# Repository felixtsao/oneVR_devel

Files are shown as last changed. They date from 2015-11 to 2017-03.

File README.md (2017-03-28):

# One VR
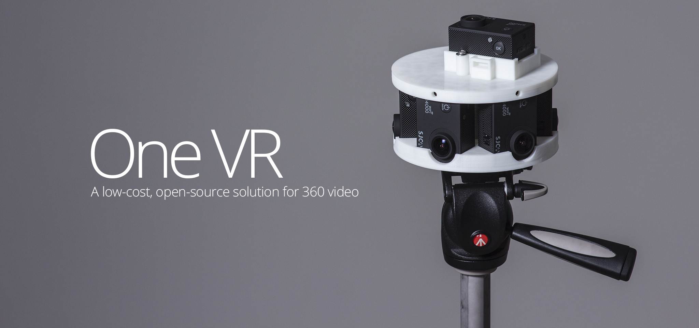
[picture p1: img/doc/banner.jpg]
Banner

<h3> A low-cost, DIY, VR/360 video solution </h3>
<p>
A low-cost, virtual reality, 360 camera system along with a mobile web 360 player application, forms an end-to-end solution; from capture to viewing.
<p>
Designs based around using off-the-shelf hardware/software. Parameterized 3D model files allow for easy generation of camera mounts to fit most small, rectangular cameras like GoPro, SJCAM, Xiaomi and NoPro. Parameterization also allows scalability to reach 4K resolution and beyond. The example SJ4000 rig costs less than $500 USD to build and achieves 4K resolution.
<p>
Video stitching methods include using accessible software and custom scripts provided by this repository.
<p>
Project started Spring break 2015 with some good friends and further developed through a Computational Photography class, CS 534. Hardware resources/funding by Garage Physics at University of Wisconsin, Madison.
<p>
<h4> Example results </h4>

[4K 60fps 8x Xiaomi Yi ITE Building](https://www.youtube.com/watch?v=hQ7O1qrUY-8) <br>
[4K 30fps 7x SJ4000 Vibration Test](https://www.youtube.com/watch?v=YHSJdiMrLIY) <br>
[4K 30fps 6x SJ4000 Madison Capitol](https://www.youtube.com/watch?v=a_FUM7AA19g)

<h3> Motivation </h3>

360 video is an exciting medium that was recently supported by video sharing sites like [YouTube](https://www.youtube.com/channel/UCzuqhhs6NWbgTzMuM09WKDQ), [Facebook](http://newsroom.fb.com/news/2015/09/introducing-360-video-on-facebook/) and [Vimeo](https://join.vimeo.com/360/?vcid=30830). Unfortunately, content creation has remained limited due the high cost-of-entry in acquiring 360 cameras and video stitching software. Professional solutions range from thousands to tens of thousands of dollars and has low accessibility. Cost-friendly, consumer 360 cameras exist on the market but are limited to sub 4K resolutions, which suffer from pixelation in 360 playback.
<p>
This repository aims to provide a high-quality solution while being accessible to 360 filmmakers on a budget. The optimal target cost for a full 360 video solution is under or around $500.
<p>
Additionally, concensus in the creative community is that a different approach from traditional filmmaking techniques must be used in developing meaningful 360 video. This is because applying panning motions and camera dollys like in traditional film may cause excessive disorientation in 360 video. Another challenge is that users may look in directions that are not intended for by the director/news-anchor.
<p>
Increasing accessibility of 360 cameras will allow more creative individuals to contemplate the artistic representation and navigation issues of 360 video. It is only beneficial to allow more people to address the challenge which can improve the collective understanding of art, filmmaking and journalism.

<h3> Pipeline </h3>
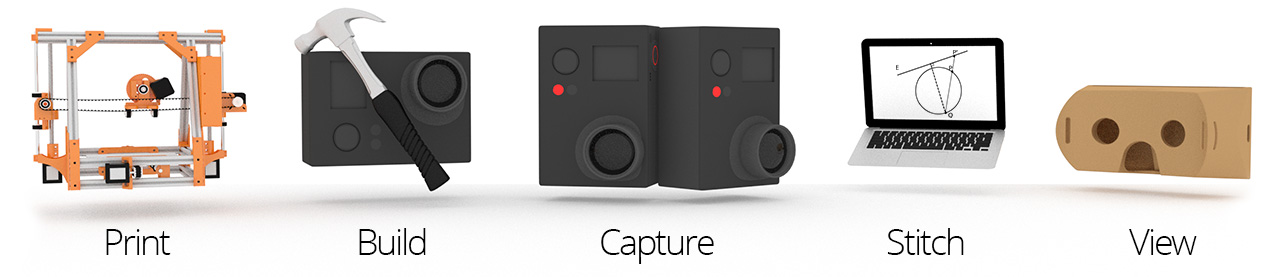
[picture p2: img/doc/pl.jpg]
Pipeline


<h3> Directories </h3>

`/360warper` - A standalone image/video warper to be used with video compositing tools like AFX, Blender, Nuke<br>
`/cam` - 3D printable 360 camera rig files (`.stl`), generator files (`.scad`) and camera control commands <br>
`/cpp` - Automated video stitching (in development, see video tutorial below for manual solution) <br>
`/img` - Documentation, reference and source images <br>
`/viewer` - Basic VR 360 video/image player for web browsers

<h3> Multi-camera system overview </h3>

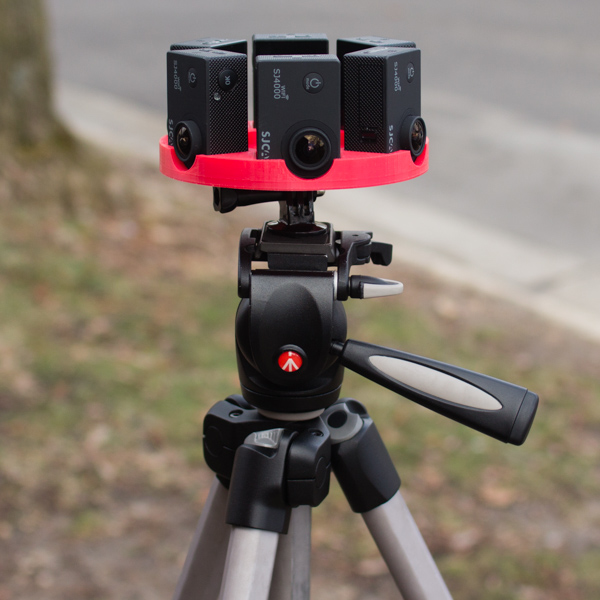
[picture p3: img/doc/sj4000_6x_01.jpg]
Version 2

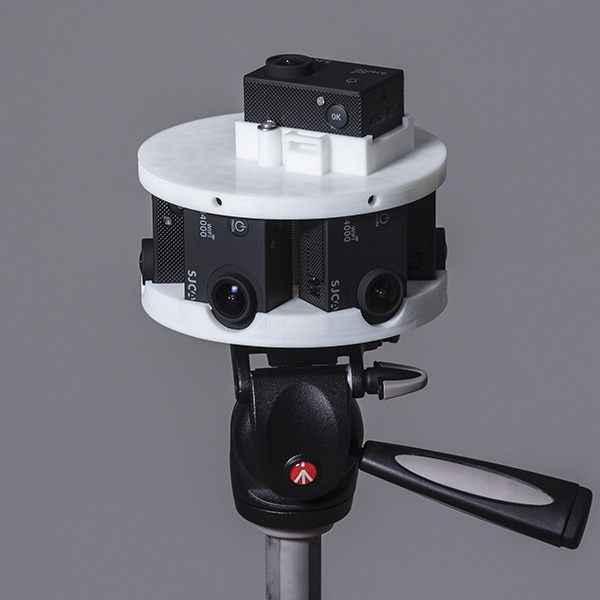
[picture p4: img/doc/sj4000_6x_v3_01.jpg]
Version 3


Version 2 left, pictured without upper mount. Version 3 on right with optional top camera expansion module.

Captures monoscopic video in 360 degrees horizontal and ~135 degrees vertical. Six individual streams are stitched and blended together into a cohesive panoramic video.
<p>
6 SJ4000 cameras arranged outwards is just barely enough information to create a 360 video and requires a decent amount of user input to stitch in After Effects. Using 5 SJ4000 cameras seated horizontally would help automated stitching a lot at the cost of some vertical field of view. Using more cameras is ideal, but drives up cost and requires a more powerful computer for stitching. Modifying lenses of the cameras with wider angle replacements is also a solution. If planning to build with out-of-box SJ4000s oriented vertically, using 8 cameras is a safe option, 7 will be bare minimum.
<p>

<h3> Bill of Materials - Hardware & Software </h3>

Listed below are items I have tested but any of them can be swapped out with other items that serve a similar purpose. Search [3DHubs](https://www.3dhubs.com) to find access to a nearby 3D printer. Some libraries have printers as well. Or build your own [RepRap](http://www.reprap.org) as a support project.

<h5> Hardware </h5>

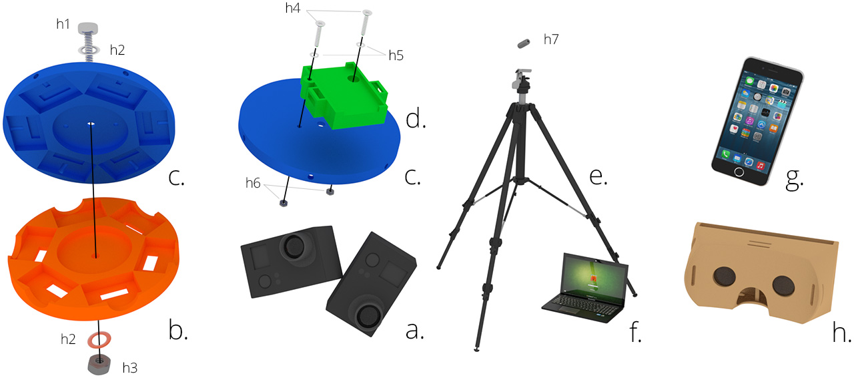
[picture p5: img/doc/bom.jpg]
Bill of Materials


<b>a.</b> 6 or more SJ4000 action cameras (~$60 each), Alternatives include GoPro, Xiaomi (may need to modify 3D models). Can use less cameras by replacing stock lenses with wide angle lenses for Xiaomi and SJ4000.
<br>
<b> b. </b> A lower bracket/apparatus to seat cameras. Modify existing CAD designs in `/cam` directory to meet camera choice.
<br>
<b> c. </b> A matching upper apparatus to secure cameras. Likewise, modify existing CAD designs in `/cam` directory to meet camera choice.
<br>
<b> d. </b> (Optional) Zenith module for housing a single additional zenith camera i.e. "Sky Camera."
<br>
<b> e. </b> Standard Tripod
<br>
<b> f. </b> Standard computer, relatively powerful GPU for image processing preferred
<br>
<b> g. </b> Any mobile device with a modern web browser
<br>
<b> h. </b> A headmounted display to house mobile device for VR viewing like [Cardboard](https://www.google.com/get/cardboard/) or print one from [Thingiverse](http://www.thingiverse.com/search?q=vr+headset).
<p>
<b> h1 </b> - 1x 1/4"-20 bolt for securing top mount to bottom mount. For SJ4000s, length of bolt must be > 3". May be different for other camera selections. Ideally, choose a length that allows bolt to stick past bottom mount an inch or two to connect to tripod with coupling bolt 'h7.'
<br>
<b> h2 </b> - 2x Washers for 1/4"-20 bolt.
<br>
<b> h3 </b> - 1x 1/4"-20 nut for tightening under bottom mount.
<p>
<i>h4 - h6 only applies if using top camera module</i>
<br>
<b> h4 </b> - 2x 6-32 screws (> 1.5" length) to mount top camera expansion module.
<br>
<b> h5 </b> - 4x #6 washers.
<br>
<b> h6 </b> - 2x 6-32 nuts.
<p>
<b> h7 </b> - 1x 1/4"-20 coupling nut for joining entire setup to tripod head.
<p>

(Optional) Switch to gen-lock/sync record controls for cameras, necessary to mitigate rolling shutter when capturing scenes with fast motion, also provides convenience for starting/stopping recording, requires soldering
<center>
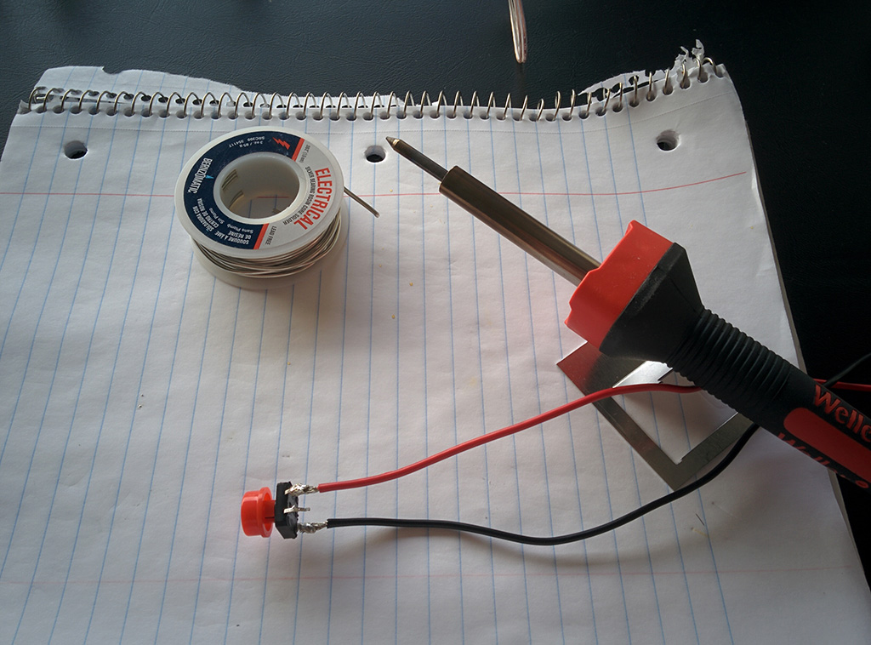
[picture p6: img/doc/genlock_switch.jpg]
Genlock Switch

<center>
<p>

<h5> Software list </h5>

 * [OpenSCAD](http://www.openscad.org) for rapid, parameterized prototyping of 3D printable VR camera mounts (Free)
 * [After Effects CC](http://www.adobe.com/products/aftereffects.html) for basic stitching using warp plugins (Free trial, then monthly subscription)
 * (Optional) Stitching plugins for After Effects like [Skybox Mettle](http://www.mettle.com/product/skybox/), [PTGui](https://www.ptgui.com/), [Kolor](http://www.kolor.com/) or [VideoStitch](http://www.video-stitch.com/) for professional stitching results (> $90)
 * [Blender](https://www.blender.org/) for alternative stitching method to After Effects, also includes capabilites to composite text and 3D. (Free)
 * [YouTube 360 Injector](https://support.google.com/youtube/answer/6178631?hl=en) for tagging proper metadata to final 360 video for properly uploading to YouTube (Free)

<h3> Stitching Techniques</h3>

[Video Tutorial: Hand-stitching in After Effects (Quick)](https://www.youtube.com/watch?v=5elOFvyL4KA) <br>
[Video Tutorial: Hand-stitching (Detailed using 360warper script)](https://www.youtube.com/watch?v=F78drmyd21I)<br>
<i>or</i> <br>
For fully automated process,compile and run stitcher in `/cpp` (still in the works) <p>

Stitcher uses ORB feature descriptor pairs to register overlapping images. ORB is also free from patent restrictions.
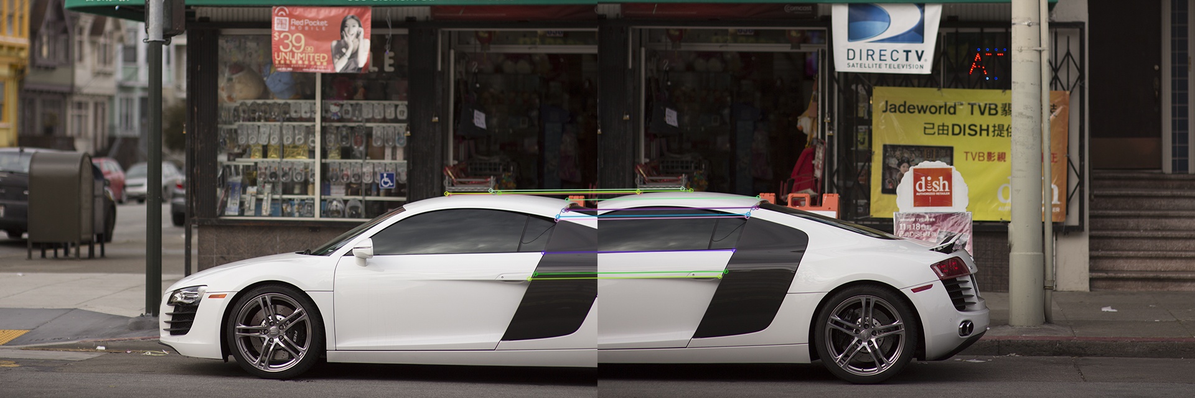
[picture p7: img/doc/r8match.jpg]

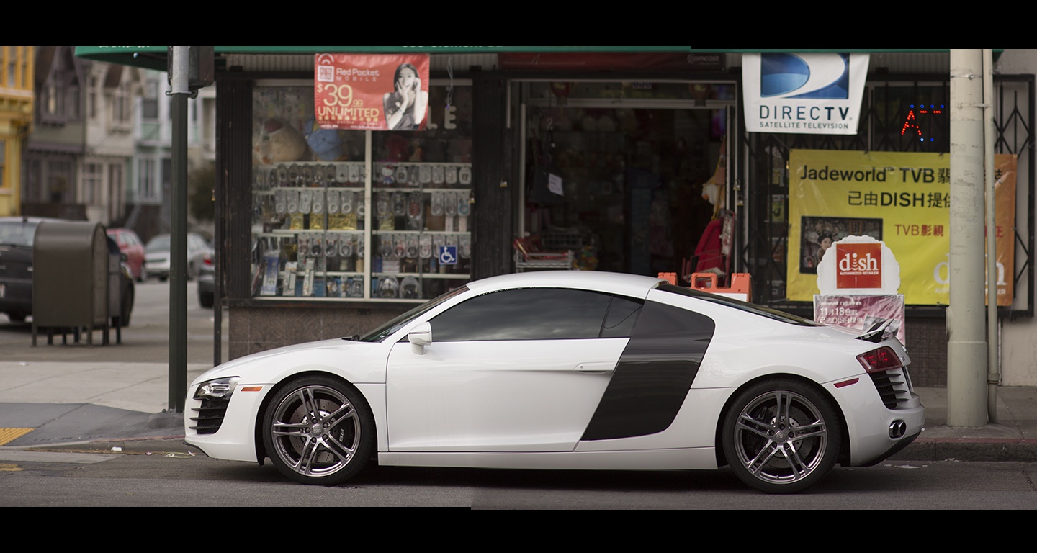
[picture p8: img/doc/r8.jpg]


<h3> Viewing </h3>

Web VR 360 Player - [Demo Link](https://cdn.rawgit.com/felixtsao/oneVR_devel/master/viewer/index.html)
<p>
Visit `/viewer` directory for usage and source code.

<h3> 3D Printing </h3>

Print camera mount yourself or find a local printer through [3DHubs](https://www.3dhubs.com) or the local library.

Older version of `mono_lower_6x_sj4000.stl` printed on a Makerbot Replicator 2 with Red PLA. The mount takes about 4 hours to print if things go smoothly! Newer version of mount printed on an open-source Prusa i3 design, right, with a layer height of 0.27mm through a 0.4mm extruder nozzle.

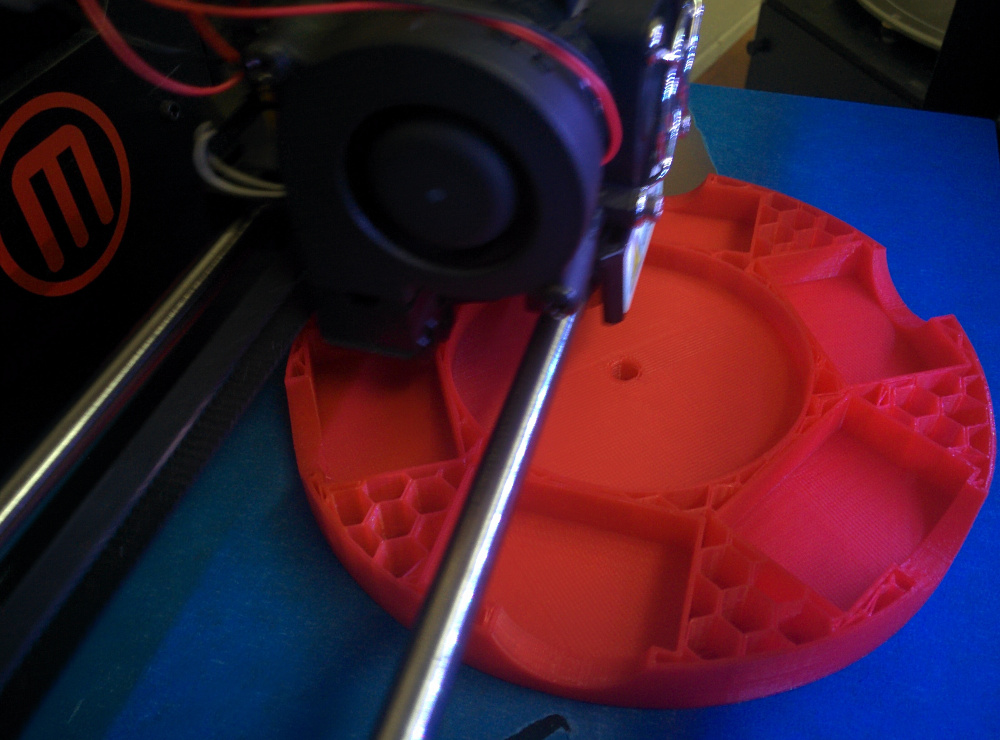
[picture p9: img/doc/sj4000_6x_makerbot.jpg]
Makerbot

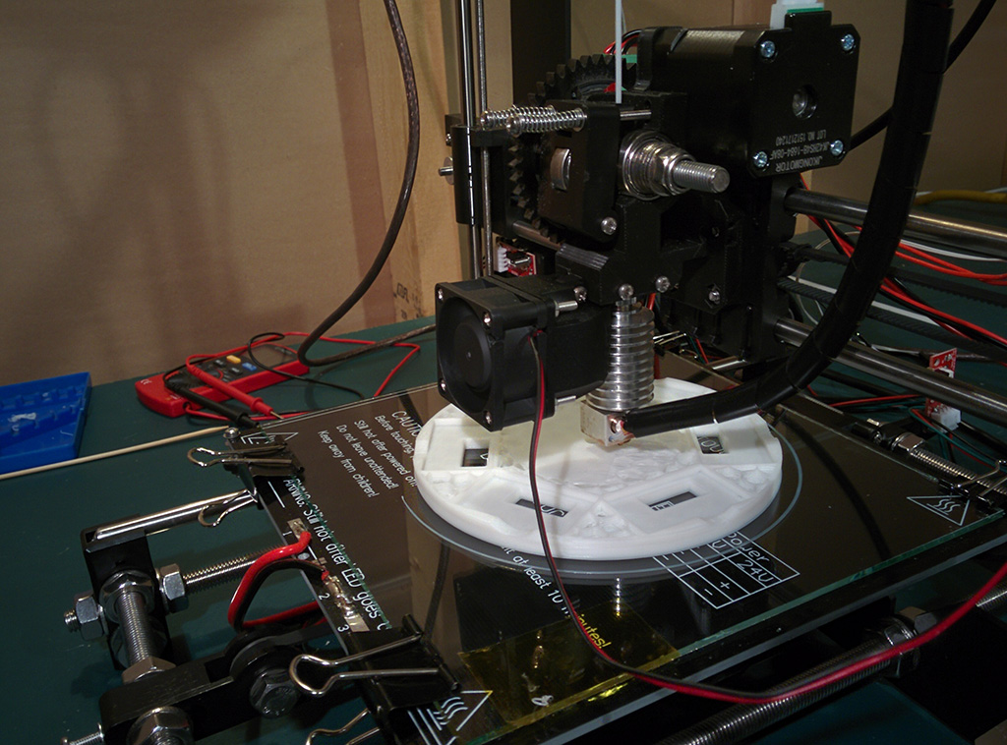
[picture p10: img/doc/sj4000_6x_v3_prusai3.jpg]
Prusa i3


<h5> Creating a new camera mount </h5>

Files are located in `/cam` directory, organized by camera model. To create a new camera mount, open the closest existing `.scad` file and adapt it by changing the camera trench dimensions. Camera dimensions are listed as variables at the top of the `.scad` files and should globally change the trench sizes across the mount. To add more cameras, simply increase the distance of the optical center and make additional copies of the trenches and assign each trench with the appropriate angle. The numbers are technically unitless but they default to millimeter for most printers. Be sure to add 1 to the value used for the camera dimension for a little breathing room.

<h3> // TODO </h3>

 * Create automated video stitching (Implement feature detector)
 * <strike>Top/bottom camera transform for AFX stitch method using Blender or script</strike><br>
 * <strike>Make video tutorial for hand-stitching 360 videos in AFX</strike>

<h3> Technical References </h3>

1) [Course: Computational Photography CS534, UW-Madison, Dyer](http://pages.cs.wisc.edu/~dyer/cs534/) <br>
2) [Text: Chapter 9, Computer Vision, Szeliski](http://szeliski.org/Book/) <br>
3) [Paper: ORB Feature Descriptor, Rublee](http://www.vision.cs.chubu.ac.jp/CV-R/pdf/Rublee_iccv2011.pdf) <br>
4) [Docs: OpenCV](http://docs.opencv.org/3.1.0/) <br>
5) [Docs: ThreeJS](https://threejs.org/) <br>
6) [Docs: RepRap](http://www.reprap.org/)

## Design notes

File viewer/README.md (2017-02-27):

# web360viewer

This viewer is deprecated. Visit [Aframe](https://aframe.io) for a better 360/VR web viewer.
<p>
#
Basic JavaScript/WebGL 360 video/photo viewer for web browsers. Works best on Chrome.
<p>
[Example](https://cdn.rawgit.com/felixtsao/oneVR_devel/master/viewer/index.html)

<h3> Brief Usage </h3>
Specify desired video/photo in file `/js/viewer.js` or rename video/photo file as `/video/src.mp4` or `/img/src.jpg`
<p>
Player default is on video mode, to view photo, set `var play_video = false;` in the file `/js/viewer.js`
<p>
Player default and current implementation only supports equirectangular projection/media. File `/js/viewer.js` includes switch for selecting projection type for future expansion i.e. cubic, pyramidal etc.
<p>
Launch `index.html` in a web browser to play. Can be hosted online and can be viewed on mobile devices using head mounted displays like cardboard.

<h3> Bugs </h3>
* May need to swipe up on the address bar to enable fullscreen on iOS devices.
* Player may appear to freeze when buffering as no buffering icon is displayed.

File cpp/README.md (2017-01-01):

# Radial Stitcher (radStitch)

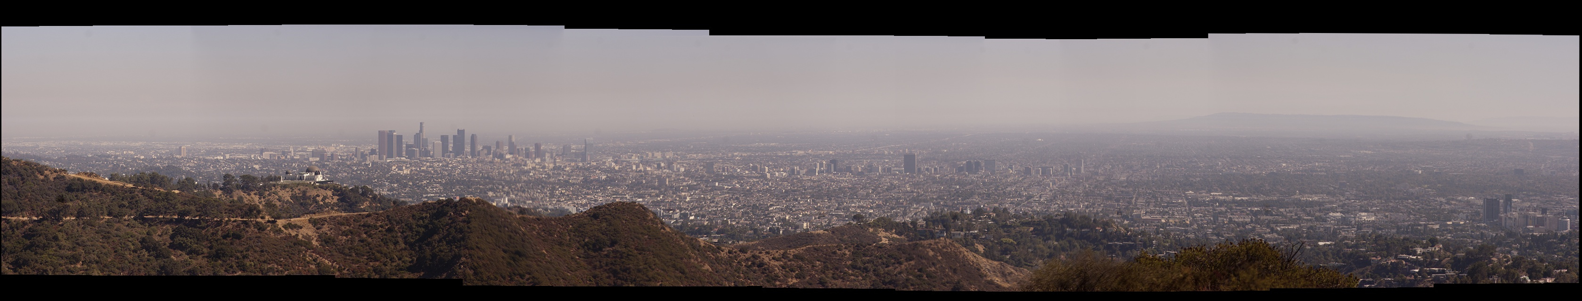
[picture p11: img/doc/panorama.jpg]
Banner


A simple panorama stitcher. Assumes input images are taken from radially symmetric viewpoints relative to common optical center--like the camera shown on the main page and like the Google Jump camera. Uses OpenCV feature description to generate matching landmarks between adjacent images. Requires OpenCV to be installed in order to compile. Works with OpenCV 3.1.0 installed on Ubuntu 16.04

<h3> Brief Usage (Ubuntu 16.04, OpenCV 3.1.0)</h3>
<i> You can probably massage this to run in Windows and macOS since using `cmake`, I haven't tried yet.</i>
<p>
To compile, make sure OpenCV is installed, and in a terminal, navigate to directory with `main.cpp` and `CMakeLists.txt`, run:
```
cmake .
```
Staying in the same directory, run:
```
make
```
After compilation, still in same directory, to stitch images, run:
```
./radStitch <image1> <image2> ... <imageN>
```
Test with images found in `/img/pano`
<p>
<i>Current constraints:</i>
<br>
Neighboring images specified in command line need to have an overlapping region i.e. `<imageK>` and `<imageK+1>` must share an overlapping region

<h3> // TODO </h3>
Currently works with images, will need to extend to video using `ffmpeg` or something
<br>
Need to implement polar wraparound
<br>
Code for parallel hardware, GPU
<br>
3D?

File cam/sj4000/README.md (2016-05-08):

<h3> Notes </h3>
SJ4000 and Elecam have the same dimensions so the mounts in this directory fit both types of cameras. However, i/o cutouts are for SJ4000 and have not been verified to be in the same locations as elecam, so usb/sdcard slots may be blocked by the mount.
<p>
Rendered `.stl` files are to be directly printed on a 3D printer. To find a local 3D printer visit [3DHubs](https://www.3dhubs.com)
<p>
Use `.scad` files in [OpenSCAD](http://www.openscad.org) (Free) to modify dimensions to match camera type and other aspects of camera mount. Render to `.stl` when finished to print.

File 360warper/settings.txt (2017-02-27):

// For additional information, check the readme.txt or
// see the accompanying YouTube tutorial at:
// https://www.youtube.com/watch?v=F78drmyd21I
//
// Settings file for 360warper. Please specify the following options below to
// let the warper know how to properly warp/project your image/video.
// You must specify the effective field of view (fov) or program will not run.
// For all other settings, if not specified in this file, 360warper will use
// the following default values: (r = up = k1 = k2 = k3 = clip = debug = 0)
// Default resolution is 4096 x 2048. You can tell the program to ignore certain
// lines of settings by typing any character at the beginning of the line. e.g.
// this comment block has "//" before each line. The setting below is ignored
// fov 120
// Be sure a setting's keyword begins immediately at the beginning of the line
// followed by a single space and then the value to guarantee proper function.
//
// resolution:
//     Target horizontal equirectangular output resolution, vertical
//     resolution is automatically chosen to be half the horizontal i.e.
//     2:1 aspect ratio
// up:
//     Enables up/top camera warping. Set true (1) to enable or set false (0) to
//     project input image/video to side/equator of sphere
// fov:
//     Effective field of view after distortion correction. This may not be
//     the same field of view advertised by camera product labels since some
//     pixels become unusable after distortion correction. See camera presets.
// k1, k2, k3:
//     Lens distortion correction values. If your camera has lens correction
//     settings from the manufacturer, it is recommended to use those and then
//     use all zeros for k1, k2, k3 for no distortion correction. Also see
//     camera presets below to use correct values for k1, k2, k3. You may also
//     experimentally determine k1, k2, k3 by taking an image of a checkerboard
//     and changing values until the lines become straight or use other
//     programs like ImageMagick, OpenCV, Numpy, Matlab etc...
// clip:
//     You usually want this on when rendering entire video streams. Set true
//     (1) to clip away any part of the frame that input image/video does not
//     project to. Set false (2) to include the rest of the 360 frame. This is
//     helpful when you want to see how a single image/video looks in 360 since
//     the frame maintains the correct proportions when shown in a 360 viewer.
// debug:
//     Draw longitude and latitude lines over warped video.

// Choose settings below
// ------------------------------------------------------------------

resolution 4096
up 0
r -90 
clip 1
debug 0
fov 97.32
k1 0.27
k2 -0.0232
k3 -0.006

// ------------------------------------------------------------------
// Choose settings above

// Presets:
// Xiaomi Yi Action Camera (Sony EXMOR R Sensor, Ambarella A7LS processor)
// fov 97.32
// k1 0.27
// k2 -0.0232
// k3 -0.006

// -----------------------------------------------------------------
// Author: hello@felixtsao.com

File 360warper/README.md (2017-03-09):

#360warper

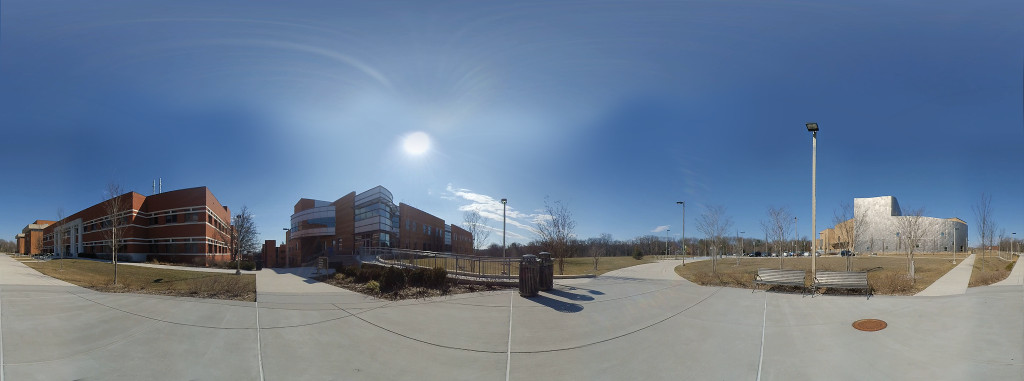
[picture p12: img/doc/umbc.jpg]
UMBC


A standalone image/video warper created to be used with video compositing tools like After Effects, Blender, Nuke etc. to create 360 video.
<p>
Transforms raw footage from camera to correct projection onto a spherical/equirectangular map for 360 video. Shown below is an example of projection to the top/north pole and projection to side/equator of the 360 viewing sphere.

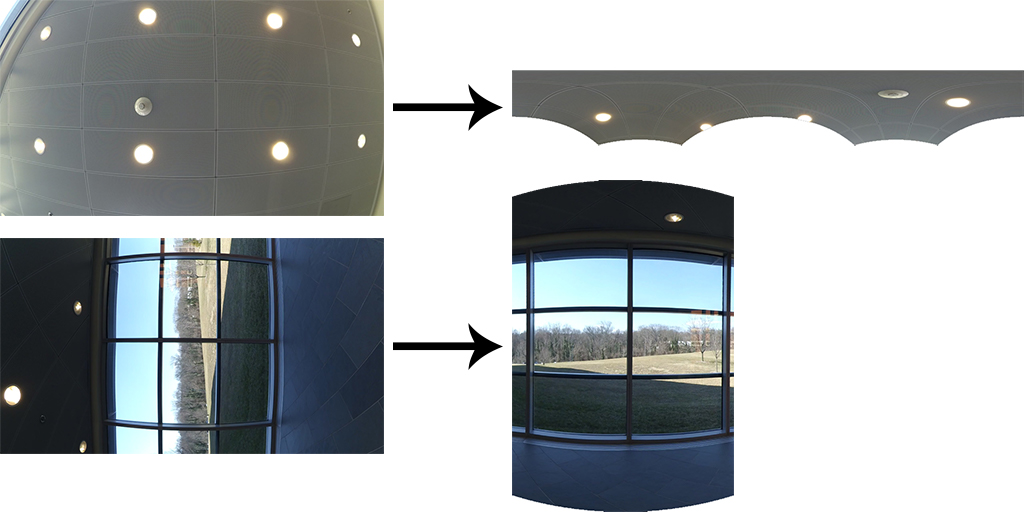
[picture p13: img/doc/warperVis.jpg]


Executables and warper script is available to download for: <br>
[macOS64](https://mega.nz/#!5UUGCYzC!riW7KApZu_tcmvv7iLBDX5ToDQJTHDBUizHfy2Ga2bs) <br>
[Win64](https://mega.nz/#!QY81lZrK!gdPLD3h7vp4k75xlDRuZmhUMljWqKGRqeY87K5DeIPQ) <br>

To see the accompanying YouTube tutorial visit:
https://www.youtube.com/watch?v=F78drmyd21I

To run warper, open a terminal and change to directory (`cd` command) containing all necessary files i.e.

    warp.py
    360warper
    settings.txt
    ffmpeg (3.2.4 included here, visit ffmpeg.org for more info)
    < Any image/video files to warp >(.mp4, .jpg, .png)

Confirm and change parameters in `settings.txt` file for desired use.

When ready to warp images/videos, type in the terminal command:

    ./warp.py video1.mp4 video2.mp4 checkerboard.jpg ...

Warping process will run. May take some time.

Process will automatically create and delete a temporary working directory called `/temp` in the same directory.

Warped videos will be saved as `originalName_warped.mp4` in same directory

Warped images will be saved as `originalName_warped.jpg` in same directory

Lens distortion correction can also be handled by `360warper`. Use the presets in the `settings.txt` file or experimentally determine the correct distortion for desired camera by taking images of several checkerboards and tweaking the distortion settings in the `settings.txt` file until it looks acceptable.

<h3> // TODO </h3>
* Pipeline and multi-thread the code more for CPU
* Implement GPU version
* Learn ffmpeg and avlib and interface directly with warper program to replace the current random python hack.

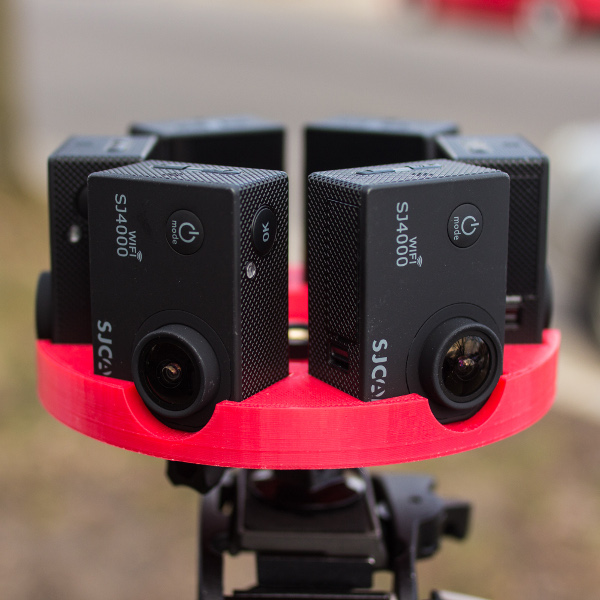
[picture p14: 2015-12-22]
img/doc/sj4000_6x_02.jpg

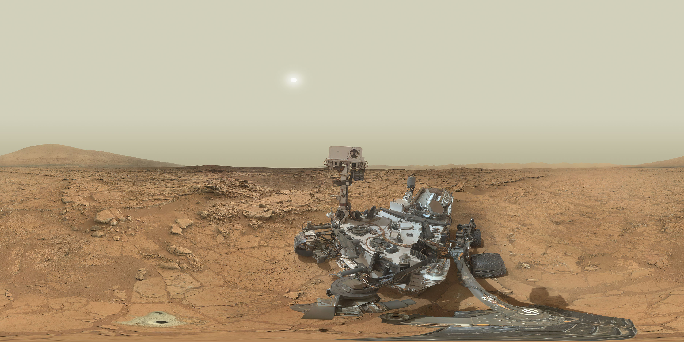
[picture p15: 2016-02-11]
viewer/img/src.jpg

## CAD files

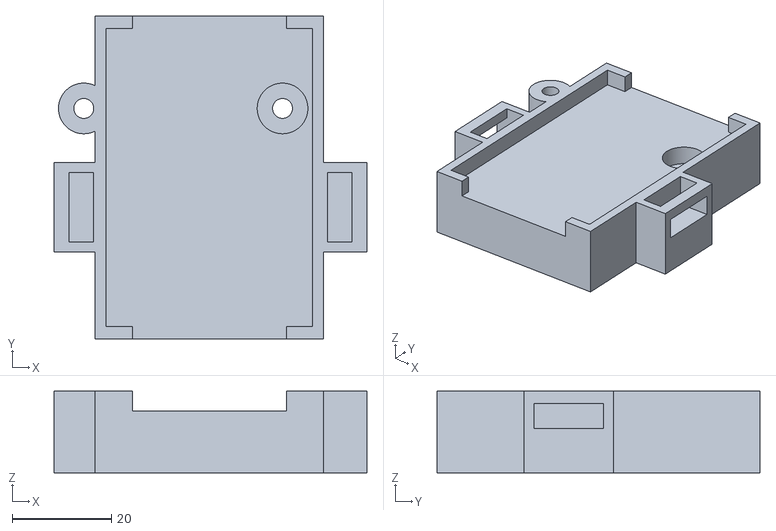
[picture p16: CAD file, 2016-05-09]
cam/sj4000/mono_zenith_sj4000.stl
63.0 x 65.0 x 16.5

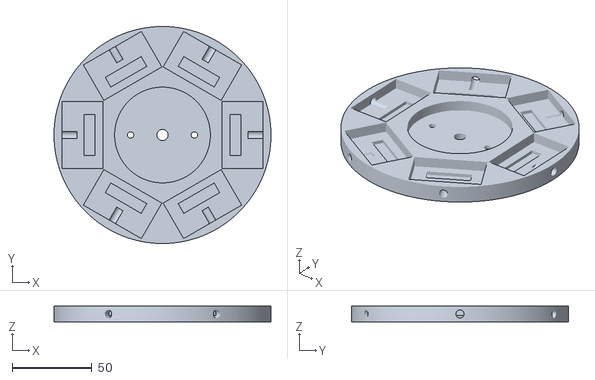
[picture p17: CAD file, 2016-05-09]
cam/sj4000_elecam/mono_upper_6x_sj4000.stl
136.0 x 136.0 x 10.0

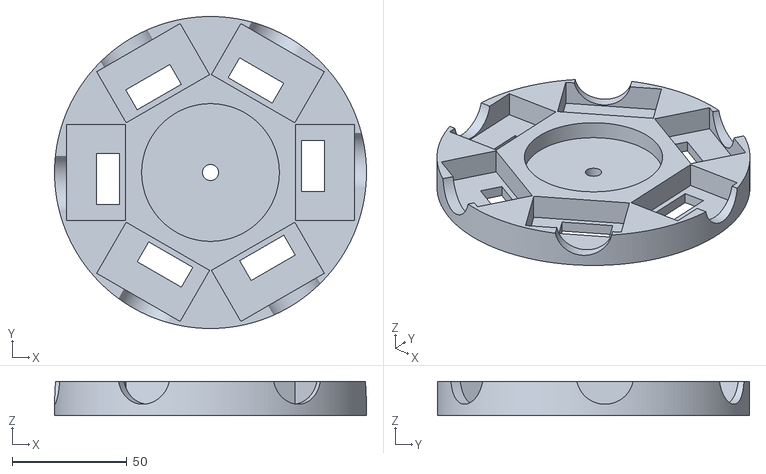
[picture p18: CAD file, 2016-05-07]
cam/sj4000_elecam/mono_lower_6x_sj4000.stl
136.0 x 136.0 x 15.0

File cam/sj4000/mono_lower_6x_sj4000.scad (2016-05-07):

$fn=200;

distance = 50; // distance from optical center

// trench dimensions (mm)
// add 1 to dimension for a little wiggle room
width = 42;
length = 25.7; 
depth = 12;

// lens cutout params
lenset = 5;
lenslift = -10;
lensdist = (distance + 12);

num_cameras = 6; // number of cameras
angular_disp = 360 / num_cameras; // angle between each camera

difference(){

    // apparatus
    cylinder(h = 15, r = 1.36 * distance, center = true);

    // trench holding camera 0
    translate([distance, 0, 3]){
        cube(size = [length, width, depth], center = true);
        translate([-5.35, 2.9, 0])
        cube(size = [10, 22.2, 100], center = true);
    }
    rotate([0,90,0])
    translate([lenslift, lenset, lensdist])
    cylinder(h = 12, r = 12.5, center = true);
 
        
    // trench holding camera 1
    rotate([0,0, angular_disp * 1]){
    translate([distance, 0, 3]){
        cube(size = [length, width, depth], center = true);
        // bottom i/o cutout
        translate([-5.35, 2.9, 0])
        cube(size = [10, 22.2, 100], center = true);
    }
    rotate([0,90,0])
    translate([lenslift, lenset, lensdist])
    cylinder(h = 12, r = 12.5, center = true);
    }

    // trench holding camera 2
    rotate([0,0, angular_disp * 2]){
    translate([distance, 0, 3]){
        cube(size = [length, width, depth], center = true);
        translate([-5.35, 2.9, 0])
        cube(size = [10, 22.2, 100], center = true);
    }
    rotate([0,90,0])
    translate([lenslift, lenset, lensdist])
    cylinder(h = 12, r = 12.5, center = true);
    }

    // trench holding camera 3
    rotate([0,0, angular_disp * 3]){
    translate([distance, 0, 3]){
        cube(size = [length, width, depth], center = true);
        translate([-5.35, 2.9, 0])
        cube(size = [10, 22.2, 100], center = true);
    }
    rotate([0,90,0])
    translate([lenslift, lenset, lensdist])
    cylinder(h = 12, r = 12.5, center = true);
    }

    // trench holding camera 4
    rotate([0,0, angular_disp * 4]){
    translate([distance, 0, 3]){
        cube(size = [length, width, depth], center = true);
        translate([-5.35, 2.9, 0])
        cube(size = [10, 22.2, 100], center = true);
    }
    rotate([0,90,0])
    translate([lenslift, lenset, lensdist])
    cylinder(h = 12, r = 12.5, center = true);
    }

    // trench holding camera 5
    rotate([0,0, angular_disp * 5]){
    translate([distance, 0, 3]){
        cube(size = [length, width, depth], center = true);
        translate([-5.35, 2.9, 0])
        cube(size = [10, 22.2, 100], center = true);
    }
    rotate([0,90,0])
    translate([lenslift, lenset, lensdist])
    cylinder(h = 12, r = 12.5, center = true);
    }

    // center dip feature
    translate([0, 0, depth - 6])
    cylinder(h = 12, r = 30, center = true);

    // clearance, not tap, hole for 1/4 20 bolt,
    cylinder(h = 30, r = 3.5, center = true);
    
    // bottom washer, nut
    translate([0, 0, depth - 6])
    cylinder(h = 12, r = 30, center = true);

}


// model sjcam4000 cameras

/*
translate([-50, 0, 27])
rotate([-90, 0, 180])
union(){ // sj400cam
    // camera body
    color("dimgray")
    cube(size = [24.7, 60, 41], center = true);

    // lens
    color("deepskyblue")
    translate([12, 16, 6])
    rotate([0,90,0])
    cylinder(h = 5, r = 10, center = true);

    // power button
    color("gray")
    translate([12, -19, 8])
    rotate([0,90,0])
    cylinder(h = 2, r = 5, center = true);

    // ok button
    color("gray")
    translate([0, -19, 21])
    cylinder(h = 2, r = 5, center = true);
}
*/

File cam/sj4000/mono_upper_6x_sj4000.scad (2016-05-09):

$fn=200;

distance = 50; // distance from optical center

// trench dimensions (mm)
// add 1 to dimension for a little wiggle room
width = 42;
length = 25.7; 
depth = 8;
lift = 3;

difference(){

    // outer radius
    cylinder(h = 10, r = 1.36 * distance, center = true);

    // camera 1 trench
    translate([distance, 0, lift]){
        union(){
            cube(size = [length, width, depth], center = true);
            translate([-4.284, 0, 0])
            cube(size = [7, 26, 12], center = true); //rocker buttons
        }

        // directional microphone cutout
        rotate([0,90,0])
        translate([3,0,11])
        cylinder(h = 15, r = 2.5, center = true);
    }

    // camera 2 trench
    rotate([0,0,60])
    translate([distance, 0, lift]){
        union(){
            cube(size = [length, width, depth], center = true);
            translate([-4.284, 0, 0])
            cube(size = [7, 26, 12], center = true); //rocker buttons
        }
        
        // directional microphone cutout
        rotate([0,90,0])
        translate([3,0,11])
        cylinder(h = 15, r = 2.5, center = true);
    }
    
    // camera 3 trench
    rotate([0,0,120])
    translate([distance, 0, lift]){
        union(){
            cube(size = [length, width, depth], center = true);
            translate([-4.284, 0, 0])
            cube(size = [7, 26, 12], center = true); //rocker buttons
        }
        
        // directional microphone cutout
        rotate([0,90,0])
        translate([3,0,11])
        cylinder(h = 15, r = 2.5, center = true);
    }

    // camera 4 trench
    rotate([0,0,180])
    translate([distance, 0, lift]){
        union(){
            cube(size = [length, width, depth], center = true);
            translate([-4.284, 0, 0])
            cube(size = [7, 26, 12], center = true); //rocker buttons
        }
        
        // directional microphone cutout
        rotate([0,90,0])
        translate([3,0,11])
        cylinder(h = 15, r = 2.5, center = true);
    }

    // camera 5 trench
    rotate([0,0,240])
    translate([distance, 0, lift]){
        union(){
            cube(size = [length, width, depth], center = true);
            translate([-4.284, 0, 0])
            cube(size = [7, 26, 12], center = true); //rocker buttons
        }
    
        // directional microphone cutout
        rotate([0,90,0])
        translate([3,0,11])
        cylinder(h = 15, r = 2.5, center = true);
    }

    // camera 6 trench
    rotate([0,0,300])
    translate([distance, 0, lift]){
        union(){
            cube(size = [length, width, depth], center = true);
            translate([-4.284, 0, 0])
            cube(size = [7, 26, 12], center = true); //rocker buttons
        }
        
        // directional microphone cutout
        rotate([0,90,0])
        translate([3,0,11])
        cylinder(h = 15, r = 2.5, center = true);
    }

    // center dip
    translate([0, 0, lift])
    cylinder(h = 8, r = 30, center = true);

    // clearance hole for 1/4 20 bolt
    cylinder(h = 20, r = 3.5, center = true);
    
    // clearance holes for optional 6-32 top camera bolt
    translate([20, 0, 0])
    cylinder(h = 20, r = 2, center = true);
    translate([-20, 0, 0])
    cylinder(h = 20, r = 2, center = true);
}


// model sjcam4000 cameras

/*
translate([-50, 0, 29.5])
rotate([90, 0, 180])
union(){ // sj400cam
    // camera body
    color("dimgray")
    cube(size = [24.7, 60, 41], center = true);

    // lens
    color("deepskyblue")
    translate([12, 16, 6])
    rotate([0,90,0])
    cylinder(h = 5, r = 10, center = true);

    // power button
    color("gray")
    translate([12, -19, 8])
    rotate([0,90,0])
    cylinder(h = 2, r = 5, center = true);

    // ok button
    color("gray")
    translate([0, -19, 21])
    cylinder(h = 2, r = 5, center = true);
}
*/

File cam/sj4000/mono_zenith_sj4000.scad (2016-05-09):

$fn = 200;


difference(){

union(){
    // stage
    translate([-17.74,-46.4,0])
    cube(size = [46,65,16.5], center = false);
        
    // 6-32 screw hole well
    translate([-20, 0, 8.25])
    cylinder(h = 16.5, r = 5.1, center = true);
    
    // velcro slot 1
    translate([-26, -28.9, 0])
    cube(size = [9,18,16.5], center = false);
    
    // velcro slot 2
    translate([28, -28.9, 0])
    cube(size = [9,18,16.5], center = false);
    
    
}

// sj4000
translate([-15.49,-43.9,12.5])
cube(size = [41.5,60,24.7], center = false);

// io, rocker cutout    
translate([-10.24,-50,12.5])
cube(size = [31,100,24.7], center = false);

// center screw head clearance
cylinder(h = 20, r = 9, center = true);
    
// 6-32 clearance for mounting screws onto upper lid
translate([20, 0, 0])
cylinder(h = 100, r = 2, center = true);
translate([-20, 0, 0])
cylinder(h = 100, r = 2, center = true);

// 6-32 counter-sink
translate([20, 0, 11])
cylinder(h = 6, r = 5.1, center = true);

// velcro cutout 1
translate([-23, -26.9, 12])
cube(size = [5,14,5], center = false);
translate([-27, -26.9, 9])
cube(size = [9,14,5], center = false);

// velcro cutout 2
rotate([0,0,180]){
translate([-34, 12.9, 12])
cube(size = [5,14,5], center = false);
translate([-38, 12.9, 9])
cube(size = [9,14,5], center = false);
}
    

}

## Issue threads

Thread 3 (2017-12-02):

6 camera rig - question

gzalles, 2017-12-02:
Do you think it is possible to stitch a 6 camera rig using your method for free? In Blender or AfterEffects?

Love your work man.

Keep it up!

felixtsao, 2017-12-11:
Yeah, should be possible, will probably take some work though.

If you're using a fairly wide angle lenses for your cameras, you'll need to remove the distortion first before stitching in AE or Blender.

gzalles, 2018-01-22:
I am using 1440 or 4k with wide FOV to get the overlap between cameras. I guess I just have to try and see if it works. I am going to give the Blender method a go (hopefully this week) and let you know how it goes!

Much respect, this contribution is fantastic.

I shared it with a friend of mine who put his own rig together!!!

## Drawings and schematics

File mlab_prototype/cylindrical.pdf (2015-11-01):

# Cylindrical Projection

x

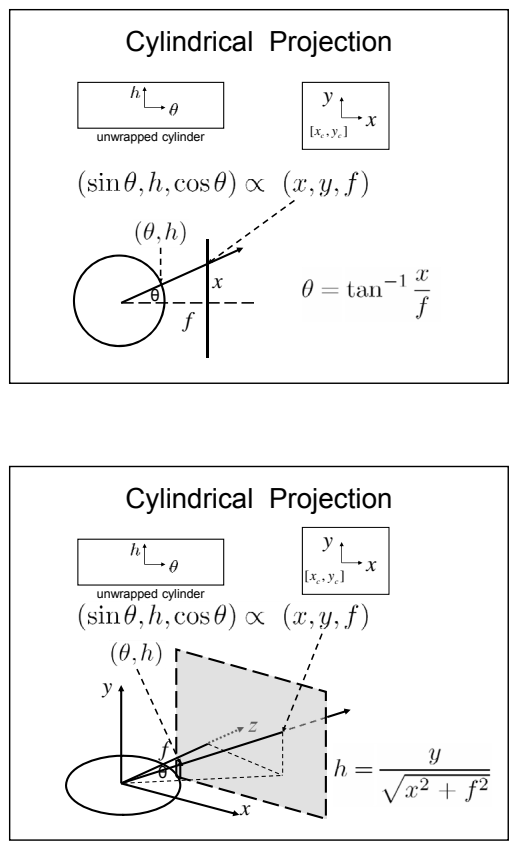
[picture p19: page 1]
[x , y ] unwrapped cylinder; Cylindrical Projection; unwrapped cylinder

# Cylindrical Projection

x

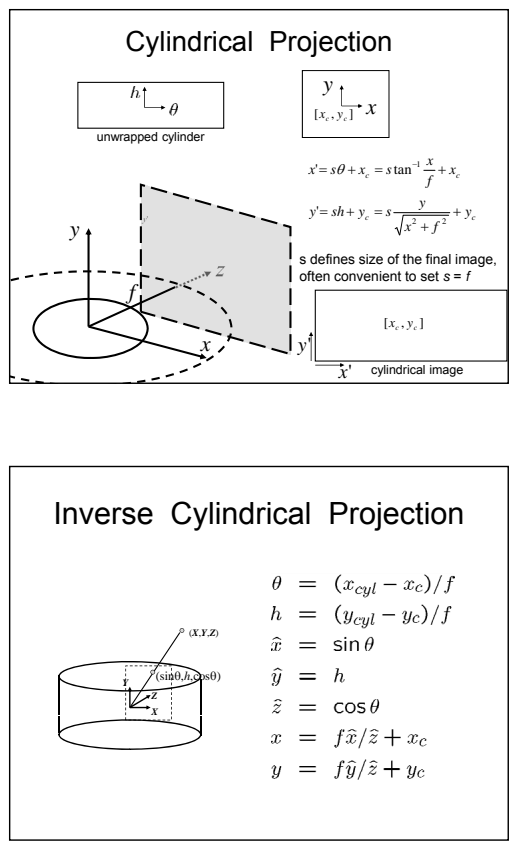
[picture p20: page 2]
unwrapped cylinder; tan; cylindrical image x'; (sinθ,h,cosθ)

s defines size of the final image
often convenient to set s = f

s defines size of the final image,

Inverse Cylindrical Projection

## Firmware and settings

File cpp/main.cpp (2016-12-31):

////////////////////////////////////////////////////////////////////////////////
//
// Program: Radial Stitcher
// Author: Felix Tsao
// Contact: hello@felixtsao.com
//
// Summary:
//
//     Simple panorama image/video stitcher. Assumes input frames are taken
//     from radially symmetric viewpoints i.e. after projection, stitching
//     challenge is reduced to recovering angles between cameras
//     i.e. translation in the video plane space.
//
//     Developed using OpenCV 3.1.0 release and Ubuntu 16.04
//
//     Written using feature descriptors from OpenCV. This code is free to be
//     copied and modified and adheres to the same OpenCV license below.
//
//
////////////////////////////////////////////////////////////////////////////////
//
//  IMPORTANT: READ BEFORE DOWNLOADING, COPYING, INSTALLING OR USING.
//
//  By downloading, copying, installing or using the software you agree to this
//  license. If you do not agree to this license, do not download, install,
//  copy or use the software.
//
//
//                           License Agreement
//                For Open Source Computer Vision Library
//
// Copyright (C) 2000-2008, Intel Corporation, all rights reserved.
// Copyright (C) 2009, Willow Garage Inc., all rights reserved.
// Third party copyrights are property of their respective owners.
//
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
//   * Redistribution's in binary form must reproduce the above copyright
//     notice, this list of conditions and the following disclaimer in the
//     documentation and/or other materials provided with the distribution.
//
//   * The name of the copyright holders may not be used to endorse or promote
//     products derived from this software without specific prior written
//     permission.
//
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
////////////////////////////////////////////////////////////////////////////////

// Standard
#include <iostream>
#include <vector>
#include <cmath>

// OpenCV - Feature Descriptors and Image I/O
#include <opencv2/opencv.hpp>
#include <opencv2/core/core.hpp>
#include <opencv2/features2d/features2d.hpp>

////////////////////////////////////////////////////////////////////////////////


// How to use this program
// -----------------------------------------------------------------------------
int usage(){
    std::cout << std::endl;
    std::cout << "Usage:" << std::endl;
    std::cout << "    ./radStitch <image1> <image2> ... <imageN>" << std::endl;
    std::cout << std::endl;
    std::cout << "Constraints:" << std::endl;
    std::cout << "    1) Stitcher assumes inputs are taken from radially symmetric viewpoints relative to a single optical center" << std::endl;
    std::cout << "    2) Specified adjacent images must overlap and share common features" << std::endl;
    std::cout << std::endl;
    exit(1);
};


// Get feature points for two adjacent images and determines matching pairs
// Uses ORB descriptor under the hood from OpenCV
// -----------------------------------------------------------------------------
int getFeatures(
    cv::Mat& img1, cv::Mat& img2,
    std::vector<cv::KeyPoint>& keypoints1, std::vector<cv::KeyPoint>& keypoints2,
    cv::Mat& descriptors1, cv::Mat& descriptors2, std::vector<cv::DMatch>& goodMatches){

    // Feature Descriptor Parameters///////////////
    int numFeatures = 2000;
    float scaleFactor = 2.0;
    int numLevels = 8;
    int edgeThreshold = 31;
    int firstLevel = 0;
    int WTA_K = 2;
    int scoreType = cv::ORB::HARRIS_SCORE;
    int patchSize = 31;
    int fastThreshold = 20;
    ///////////////////////////////////////////////

    cv::Ptr<cv::ORB> detector = cv::ORB::create(
        numFeatures,
        scaleFactor,
        numLevels,
        edgeThreshold,
        firstLevel,
        WTA_K,
        scoreType,
        patchSize,
        fastThreshold);

    detector->detectAndCompute(img1, cv::Mat(), keypoints1, descriptors1);
    detector->detectAndCompute(img2, cv::Mat(), keypoints2, descriptors2);

    // Determine matching pairs via Euclidean distance
    cv::BFMatcher matcher(cv::NORM_L2);
    std::vector<cv::DMatch> matches;
    matcher.match(descriptors1, descriptors2, matches);

    // Quick calculation of max and min distances between keypoints
    double max_dist = 0; double min_dist = 100;
    for(int i = 0; i < descriptors1.rows; i++){
        double dist = matches[i].distance;
        if(dist < min_dist) min_dist = dist;
        if(dist > max_dist) max_dist = dist;
    }

    // Draw only "good" matches i.e. those that are less than 3 * min_dist
    for(int i = 0; i < descriptors1.rows; i++){
        if(matches[i].distance < 3 * min_dist) goodMatches.push_back(matches[i]);
    }

    cv::Mat img_matches;
    drawMatches(img1, keypoints1, img2, keypoints2,
        goodMatches, img_matches, cv::Scalar::all(-1), cv::Scalar::all(-1),
        std::vector<char>(), cv::DrawMatchesFlags::NOT_DRAW_SINGLE_POINTS );

    // Localize the object
    /*
    std::vector<cv::Point2f> img1pt;
    std::vector<cv::Point2f> img2pt;
    for(int i = 0; i < (int) goodMatches.size(); i++){
        // Get the keypoints from the good matches
        img1pt.push_back(keypoints1[goodMatches[i].queryIdx].pt);
        img2pt.push_back(keypoints2[goodMatches[i].trainIdx].pt);
    }
    */

    //cv::imshow("Matches", img_matches);
    //imwrite("match.jpg", img_matches);
    //cv::waitKey(0);

    return 0;

}


// Projects an image onto a cylindrical surface with specified focal length
// -----------------------------------------------------------------------------
int projectCylindrical(cv::Mat &I, cv::Mat&O, double f){

    int nRows = I.rows;
    int nCols = I.cols;

    int xCenter = nCols / 2;
    int yCenter = nRows / 2;

    int x, y;
    uchar *sI;
    uchar *sO;

    // For every pixel in cylindrical projection
    for (y = 0; y < nRows; y++) {
        for (x = 0; x < nCols; x++) {

            double theta = (x - xCenter) / f;
            double h = (y - yCenter) / f;
            double xp = sin(theta);
            double yp = h;
            double zp = cos(theta);

            // Get pixel from input image
            int xIn = round(f * xp / zp + xCenter);
            int yIn = round(f * yp / zp + yCenter);

            // In bounds?
            sO = O.ptr<uchar>(y);
            if(xIn > -1 && xIn < nCols && yIn > -1 && yIn < nRows){
                sI = I.ptr<uchar>(yIn);
                // 3 Channel BGR
                sO[3*x] = sI[3*xIn]; // Blue
                sO[3*x + 1] = sI[3*xIn + 1]; // Green
                sO[3*x + 2] = sI[3*xIn + 2]; // Red
            }
        }
    }

    return 0;

}


// Projects an image onto a spherical surface, returns warped image
// -----------------------------------------------------------------------------
int projectSpherical(cv::Mat &I, cv::Mat&O, double f){

    int nRows = I.rows;
    int nCols = I.cols;

    int xCenter = nCols / 2;
    int yCenter = nRows / 2;

    int x, y;
    uchar *sI;
    uchar *sO;

    // Inverse spherical projection
    // For every pixel in spherical projection
    // TODO can probably optimize this
    for (y = 0; y < nRows; y++) {
        for (x = 0; x < nCols; x++) {

            double theta = (x - xCenter) / f;
            double phi = (y - yCenter) / f;
            double xp = sin(theta) * cos(phi);
            double yp = sin(phi);
            double zp = cos(theta) * cos(phi);

            // Get pixel from input image
            int xIn = round(f * xp / zp + xCenter);
            int yIn = round(f * yp / zp + yCenter);

            // In bounds?
            sO = O.ptr<uchar>(y);
            if(xIn > -1 && xIn < nCols && yIn > -1 && yIn < nRows){
                sI = I.ptr<uchar>(yIn);
                // 3 Channel RGB
                sO[3*x] = sI[3*xIn]; // Blue
                sO[3*x + 1] = sI[3*xIn + 1]; // Green
                sO[3*x + 2] = sI[3*xIn + 2]; // Red
            }
        }
    }

    return 0;

}


// Projects a mask onto a spherical surface, returns warped mask
// -----------------------------------------------------------------------------
int projectMaskSpherical(cv::Mat &I, cv::Mat&O, double f){

    int nRows = I.rows;
    int nCols = I.cols;

    int xCenter = nCols / 2;
    int yCenter = nRows / 2;

    int x, y;
    double *sI;
    double *sO;

    // Inverse spherical projection
    // For every pixel in spherical projection
    for (y = 0; y < nRows; y++) {
        for (x = 0; x < nCols; x++) {

            double theta = (x - xCenter) / f;
            double phi = (y - yCenter) / f;
            double xp = sin(theta) * cos(phi);
            double yp = sin(phi);
            double zp = cos(theta) * cos(phi);

            // Get pixel from input image
            int xIn = round(f * xp / zp + xCenter);
            int yIn = round(f * yp / zp + yCenter);

            // In bounds?
            sO = O.ptr<double>(y);
            if(xIn > -1 && xIn < nCols && yIn > -1 && yIn < nRows){
                sI = I.ptr<double>(yIn);
                sO[x] = sI[xIn];
            }
        }
    }

    return 0;

}


// Compute translation homography between 2 adjacent images
// -----------------------------------------------------------------------------
int estimateHomography(
    std::vector<cv::KeyPoint>& kpNew, std::vector<cv::KeyPoint>& kpCur,
    std::vector<cv::DMatch>& matches, cv::Mat& homography){

    int nMatches = (int) matches.size();

    std::cout << nMatches << " feature point matches" << std::endl;

    //int trials = 500;
    int trials = nMatches;
    double xTrans = 0;
    double yTrans = 0;
    double tolerance = 3.0; // pixels
    int xQual = 0, yQual = 0; // 0 for bad, 1 for good, within tolerance
    int concensus = 0;
    int maxConcensus = 0;
    int bestX = 0;
    int bestY = 0;

    srand(0);


    // RANSAC

    if(nMatches < trials) std::cout << "Less matches than trials" << std::endl;

    // Estimate quality is high at around 500 iterations
    for (int i = 0; i < trials; i++) {

        // Inititialize
        xQual = 0;
        yQual = 0;
        concensus = 0;

        int featureNumber = rand() % nMatches; // Choose random feature pair
        //std::cout << "ftNumb " << featureNumber << std::endl;

        // Use as reference
        double xReferenceNew = kpNew[matches[featureNumber].queryIdx].pt.x;
        double xReferenceCur = kpCur[matches[featureNumber].trainIdx].pt.x;
        double yReferenceNew = kpNew[matches[featureNumber].queryIdx].pt.y;
        double yReferenceCur = kpCur[matches[featureNumber].trainIdx].pt.y;

        // Shift estimate
        xTrans = xReferenceCur - xReferenceNew;
        yTrans = yReferenceCur - yReferenceNew;
        //std::cout << "xTrans " << xTrans << std::endl;
        //std::cout << "yTrans " << yTrans << std::endl;

        // Check against all other features
        for (int j = 0; j < nMatches; j++) {

            if (j == featureNumber) continue; // Skip reference feature

            // Estimate x translation
            double xNew = kpNew[matches[j].queryIdx].pt.x;
            double xCur = kpCur[matches[j].trainIdx].pt.x;
            double xEstimate = xCur - xNew;
            //std::cout << "xEstimate " << xEstimate << std::endl;

            // Estimate y translation
            double yNew = kpNew[matches[j].queryIdx].pt.y;
            double yCur = kpCur[matches[j].trainIdx].pt.y;
            double yEstimate = yCur - yNew;
            //std::cout << "yEstimate " << yEstimate << std::endl;

            // Check if estimate is good against ground truth
            //std::cout << "diffX " << fabs(xTrans - xEstimate) << std::endl;
            //std::cout << "diffY " << fabs(yTrans - yEstimate) << std::endl;
            if(fabs(xTrans - xEstimate) < tolerance) xQual = 1;
            if(fabs(yTrans - yEstimate) < tolerance) yQual = 1;
            if(xQual && yQual) concensus++;

        }

        if(concensus > maxConcensus){
            //std::cout << "ever?" << std::endl;
            maxConcensus = concensus;
            bestX = xTrans;
            bestY = yTrans;
        }

    }

    /*
    // Averaging translation
    //matches = 1; // temp override for testing, delete this later
    for (int i = 0; i < nMatches; i++) {

        double xNew = kpNew[matches[i].queryIdx].pt.x;
        double xCur = kpCur[matches[i].trainIdx].pt.x;
        xTrans += xCur - xNew;

        double yNew = kpNew[matches[i].queryIdx].pt.y;
        double yCur = kpCur[matches[i].trainIdx].pt.y;
        yTrans += yCur - yNew;

    }
    */

    // If no good concensus, just pick the most recent reference
    if (bestX == 0)
        bestX = xTrans;
    if (bestY == 0)
        bestY = yTrans;

    homography.at<double>(0, 2) = bestX;
    homography.at<double>(1, 2) = bestY;
    //std::cout << bestX << std::endl;
    //std::cout << bestY << std::endl;

    return 0;

}


// Makes an alpha/feathering mask for a given image
// Pixels in center of image have alpha value 1 and linearly decreases to 0
// towards edges of image
// -----------------------------------------------------------------------------
int buildBlendMask(cv::Mat& img, cv::Mat& mask){

    if(img.size() != mask.size()) return -1; // Check same size

    int nRows = mask.rows;
    int nCols = mask.cols;
    int maxDist = 0;

    if(nRows > nCols) maxDist = nCols / 2;
    else maxDist = nRows / 2;

    mask = cv::Scalar(0, 0, 0); // No alpha yet

    double* row;

    int distLeft, distRight, distTop, distBottom; // Distances from edge of image

    // Compute alpha intensity for each pixel in mask
    for (int y = 0; y < nRows; y++) {
        row = mask.ptr<double>(y);
        distTop = abs(y + 1);
        distBottom = abs(nRows - y - 1);
        int yDist = std::min(distTop, distBottom);
        for (int x = 0; x < nCols; x++) {
            distLeft = abs(x + 1);
            distRight = abs(nCols - x - 1);
            int xDist = std::min(distLeft, distRight);
            row[x] = (double) std::min(xDist, yDist) / (double) maxDist; // alpha
        }
    }

    return 0;

}


// Blend 2 images together, both should have same size/bounding box
// Current implementation assumes only blending with left neighbor
// -----------------------------------------------------------------------------
int blend(cv::Mat& newImage, cv::Mat& canvas, cv::Mat& newMask, cv::Mat& canvasMask){

    /*
    imshow("newImage", newImage);
    waitKey(0);
    imshow("pano", canvas);
    waitKey(0);
    imshow("newMask", newMask);
    waitKey(0);
    imshow("canvasMask", canvasMask);
    waitKey(0);
    */

    if(newImage.size() != canvas.size()) return -1; // Check same size

    int nRows = canvas.rows;
    int nCols = canvas.cols;

    uchar* rowCan; // Row in canvas/output panorama to update
    uchar* rowNew; // Row in new image to blend in
    double* alphaCan; // Alpha value of canvas/panorama
    double* alphaNew; // Alpha value of new image

    for (int y = 0; y < nRows; y++) {
        rowCan = canvas.ptr<uchar>(y);
        rowNew = newImage.ptr<uchar>(y);
        alphaCan = canvasMask.ptr<double>(y);
        alphaNew = newMask.ptr<double>(y);
        for (int x = 0; x < nCols; x++) {
            if(rowCan[3*x] != 0 && rowNew[3*x] != 0){ // Feather region
                double aN = alphaNew[x];
                double aC = alphaCan[x];
                rowCan[3*x] = (aN * rowNew[3*x] + aC * rowCan[3*x]) / (aN + aC); // Blue
                rowCan[3*x + 1] = (aN * rowNew[3*x + 1] + aC * rowCan[3*x + 1]) / (aN + aC); // Green
                rowCan[3*x + 2] = (aN * rowNew[3*x + 2] + aC * rowCan[3*x + 2]) / (aN + aC); // Red
            } else if (!(rowCan[3*x] > 0)) {
                rowCan[3*x] = rowNew[3*x];
                rowCan[3*x + 1] = rowNew[3*x + 1];
                rowCan[3*x + 2] = rowNew[3*x + 2];
            }
        }
    }

    return 0;

}


// Projection options
// -----------------------------------------------------------------------------
enum Projection { CYLINDRICAL, SPHERICAL };


// Panorama stitcher program
// -----------------------------------------------------------------------------
int main(int argc, char ** argv) {

    if(argc < 3) usage(); // Need at least 2 images
    int numImages = argc - 1;

    std::cout << "Stitching " << numImages << " images..." << std::endl;

    // Project and store input images ------------------------------------------

    double f = 600; // Camera focal length parameter (unknown units, not mm)
    //f = 2800; // LA skyline lens (300mm ish)
    f = 10000000000; // SF Marin Headlands (Moto G4)
    Projection projection = SPHERICAL;
    std::vector<cv::Mat> src; // Store input images
    std::vector<cv::Mat> blendMasks; // Store alpha channel blend masks for images
    std::vector<cv::Mat> hStack; // Translation matrices for all images rel. to 1st

    for (int i = 0; i < numImages; i++) {

        cv::Mat temp = cv::imread(argv[i + 1], 1);
        cv::Mat mask = cv::Mat::zeros(temp.rows, temp.cols, CV_64F);
        buildBlendMask(temp, mask);

        if(!temp.data) usage(); // Image is legit?

        src.push_back(cv::Mat::zeros(temp.rows, temp.cols, temp.type()));
        blendMasks.push_back(cv::Mat::zeros(mask.rows, mask.cols, mask.type()));

        // Project image and its blend mask
        if(projection == SPHERICAL){
            projectSpherical(temp, src[i], f);
            projectMaskSpherical(mask, blendMasks[i], f);
        } else {
            projectCylindrical(temp, src[i], f);
            projectCylindrical(mask, blendMasks[i], f);
        }
    }

    // Use first image to start panorama
    cv::Mat center = src[0];

    // Output mosaic/canvas
    cv::Mat out = cv::Mat::zeros(1.2 * center.rows, center.cols + ((numImages - 1) * 0.5 * center.cols), center.type());

    // 3x3 Identity
    cv::Mat Id = (cv::Mat_<double>(3,3) <<
        1, 0, 0,
        0, 1, 0,
        0, 0, 1);

    // Center first image
    double xCenter = 0;
    double yCenter = -center.rows/2 + out.rows/2;

    cv::Mat Tr = (cv::Mat_<double>(3,3) << // Translation to center first image of panorama
        1, 0, xCenter,
        0, 1, yCenter,
        0, 0, 1);

    hStack.push_back(Tr); // First homography for first input image

    // Warp in first image
    warpPerspective(center, out, Tr, out.size());

    // Stitch remaining images in relative to first image
    for (int i = 1; i < numImages; i++) {

        cv::Mat curr = src[i]; // Current image to stitch in...
        cv::Mat left = src[(i - 1) % numImages]; // ...And its left neighbor image

        std::vector<cv::KeyPoint> keypoints1; // curr's keypoints
        std::vector<cv::KeyPoint> keypoints2; // neighbors's keypoints
        cv::Mat descriptors1; // curr's
        cv::Mat descriptors2; // neighbor's
        std::vector<cv::DMatch> matches;

        getFeatures(curr, left, keypoints1, keypoints2, descriptors1, descriptors2, matches);

        cv::Mat H = (cv::Mat_<double>(3,3) << // Modify this to relate curr image to neighbor
            1, 0, 0,
            0, 1, 0,
            0, 0, 1);

        estimateHomography(keypoints1, keypoints2, matches, H); // Find translation

        cv::Mat warped = cv::Mat::zeros(out.rows, out.cols, out.type()); // Translated image
        cv::Mat newMask = cv::Mat::zeros(out.rows, out.cols, CV_64F);

        // Use this matrix to find the chain of transformations relating curr
        // image to the first image
        cv::Mat C = (cv::Mat_<double>(3,3) <<
            1, 0, 0,
            0, 1, 0,
            0, 0, 1);

        // Stack all previous translations and...
        C.at<double>(0, 2) += hStack[i - 1].at<double>(0, 2);
        C.at<double>(1, 2) += hStack[i - 1].at<double>(1, 2);

        //...add new homography for curr image
        C.at<double>(0, 2) += H.at<double>(0, 2);
        C.at<double>(1, 2) += H.at<double>(1, 2);

        hStack.push_back(C);
        warpPerspective(curr, warped, C, warped.size()); // Warp curr image
        warpPerspective(blendMasks[i], newMask, C, newMask.size()); // And its mask
        //std::cout << "here?" << std::endl;

        // Get its left neighbor's mask
        cv::Mat prevMask = cv::Mat::zeros(out.rows, out.cols, CV_64F);
        warpPerspective(blendMasks[i - 1], prevMask, hStack[i - 1], prevMask.size());

        // Blend and add to panorama
        //out = 0.5 * warped + 0.5 * out; // Add to panorama
        blend(warped, out, newMask, prevMask);

    }

    cv::imwrite("panorama.jpg", out);

    //cv::imshow("panorama", out);
    //cv::waitKey(0);



    return 0;

}

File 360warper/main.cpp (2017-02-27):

////////////////////////////////////////////////////////////////////////////////
//
// Program: 360warper
// Author: Felix Tsao
// Contact: hello@felixtsao.com
//
// Summary:
//
//     Warper for 360 photo/video stitching
//     Takes an image/sequences and outputs corresponding spherical projection
//     Uses radial model for fixing distortion
//     Assumes a radially symmetric camera model like images shown at
//     (github.com/felixtsao/oneVR_devel)
//     i.e. lateral cameras all in the same plane and single up/down cameras
//
//     User must specify to project input image as up/down camera or side camera
//     and FOV in degrees, and 2 distortion correction paramters. See comments
//     in code.
//
//     This software uses the CImg library and follows the same open-source
//     license that it uses.
//
////////////////////////////////////////////////////////////////////////////////

#include <iostream>
#include <fstream>
#include <sstream>
#include <vector>
#include <string>
#include <omp.h>
#include "SphericalWarper.hpp"


void usage(){
    std::cout << '\n';
    std::cout << " 360 Warp Assistant v1.0" << '\n';
    std::cout << "--------------------------------------------------------------------------------" << '\n';
    std::cout << '\n';
    std::cout << "    To see the accompanying YouTube tutorial, visit:" << '\n';
    std::cout << "    https://www.youtube.com/watch?v=F78drmyd21I" << '\n';
    std::cout << '\n';
    std::cout << "    This binary is not intended to be run without its python manager script." << '\n';
    std::cout << "    Please run warp.py to warp a video/image file." << '\n';
    std::cout << '\n';
    std::cout << "    The following files must be in the same directory to work." << '\n';
    std::cout << "        warp.py, 360warper, settings.txt and ffmpeg" << '\n';
    std::cout << '\n';
    std::cout << "    Choose warper settings by configuring the 'settings.txt' file." << '\n';
    std::cout << "    Horizontal output resolution (output), field of view (fov), rotation (r)," << '\n';
    std::cout << "    projection direction--side (up 0) or to north pole (up 1)-- and distortion" << '\n';
    std::cout << "    correction constants (k1, k2, k3) must be specified in 'settings.txt'" << '\n';
    std::cout << '\n';
    exit(1);
}


int main(int argc, char ** argv) {

    // Check for key to prevent accidental misuse of program
    if(argc != 2) usage();
    std::string key = argv[1];
    if(key != "-k") usage();

    int width = 4096;
    double fov = -1;
    double r = 0;
    bool chooseUp = false;
    double k1 = 0;
    double k2 = 0;
    double k3 = 0;
    bool clip = false;
    bool debug = false;

    // Get settings from settings.txt file
    std::ifstream settings("settings.txt", std::ios::in);
    if (settings.is_open()){

        std::string buffer, word;

        while (std::getline(settings, buffer)){

            std::stringstream ss(buffer);
            ss >> word;

            if(word == "fov"){
                ss >> word;
                fov = std::stod(word);
                if(fov > 170 || fov < 0) usage();
            } else if (word == "r"){
                ss >> word;
                r = std::stod(word);
            } else if (word == "up"){
                ss >> word;
                chooseUp = (bool) std::stoi(word);
            } else if (word == "k1"){
                ss >> word;
                k1 = std::stod(word);
            } else if (word == "k2"){
                ss >> word;
                k2 = std::stod(word);
            } else if (word == "k3"){
                ss >> word;
                k3 = std::stod(word);
            } else if (word == "resolution"){
                ss >> word;
                width = std::stoi(word);
                if(width < 0) usage();
            } else if (word == "clip"){
                ss >> word;
                clip = (bool) std::stoi(word);
            } else if (word == "debug"){
                ss >> word;
                debug = (bool) std::stoi(word);
            }

        }

        settings.close();

    } else { usage(); }

    std::ifstream frameList("temp/input.txt", std::ios::in);
    if (frameList.is_open()){

        std::string lineIn;
        std::vector<std::string> fileNames;
        while (std::getline(frameList, lineIn)){
            fileNames.push_back(lineIn);
        }

        int nFrames = fileNames.size();

        SphericalWarper * s1 = new SphericalWarper(fileNames[0], width, fov, r, chooseUp, k1, k2, k3, clip, debug);
        //SphericalWarper * s2 = new SphericalWarper(fileNames[0], width, fov, r, chooseUp, k1, k2, k3, clip, debug);
        //SphericalWarper * s3 = new SphericalWarper(fileNames[0], width, fov, r, chooseUp, k1, k2, k3, clip, debug);
        //SphericalWarper * s4 = new SphericalWarper(fileNames[0], width, fov, r, chooseUp, k1, k2, k3, clip, debug);

        for (int i = 0; i < nFrames; i++) {
            s1->warp(fileNames[i]);
        }

        /*
        for (int i = 0; i < nFrames / 4; i += 4) {
            for (int j = 0; j < 4; j++) {
                s1->warp(fileNames[i + j]);
            }
            for (int j = 0; j < 4; j++) {
                s1->save(fileNames[i + j]);
            }
        }
        */

        /*
        // 4 threads
        #pragma omp parallel
        {

            #pragma omp single
            {
                for (int i = 0; i < nFrames / 4; i++) {
                    s1->warp(fileNames[i]);
                }
            }

            #pragma omp single
            {
                for (int i = nFrames / 4; i < nFrames / 2; i++) {
                    s2->warp(fileNames[i]);
                }
            }

            #pragma omp single
            {
                for (int i = nFrames / 2; i < 3 * nFrames / 4; i++) {
                    s3->warp(fileNames[i]);
                }
            }

            #pragma omp single
            {
                for (int i = 3 * nFrames / 4; i < nFrames; i++) {
                    s4->warp(fileNames[i]);
                }
            }

        }
        */

        frameList.close();

    } else { usage(); }


    return 0;

}

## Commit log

2015-12-04 added cad designs for camera mount and restructured folder organization
    [horz_lower.scad, horz_upper.scad, mono_full.scad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]
2015-12-18 added updated dimensions for cad files and restructured folders
    [mono_lower6.scad, mono_lower6.stl, mono_upper6.scad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]
2015-12-21 add cpp and restructure folders
    [horz_lower.scad, horz_upper.scad, mono_full.scad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]
2015-12-22 folder restructure
    [horz_lower.scad, horz_upper.scad, mono_full.scad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]
2015-12-22 add cad files for sj4000 cameras
    [mono_lower_6x_sj4000.scad, mono_lower_6x_sj4000.stl, mono_upper_6x_sj4000.scad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]
2015-12-22 added more ref pics to cad
2015-12-26 added more parameterized features for .scad VR camera mount generator files
    [mono_lower_8x_sj4000.scad, mono_lower_8x_sj4000.stl]
2016-01-25 restructure dirs
    [mono_lower_6x_sj4000.scad, mono_lower_6x_sj4000.stl, mono_lower_8x_sj4000.scad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]
2016-01-25 rm cad
    [mono_lower_6x_sj4000.scad, mono_lower_6x_sj4000.stl, mono_lower_8x_sj4000.scad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]
2016-03-03 rename dir sj4000 mounts also work for elecam
    [mono_lower_6x_sj4000.scad, mono_lower_6x_sj4000.stl, mono_lower_8x_sj4000.scad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]
2016-05-07 added io cutouts and changed clearance (holes and buttons)
    [mono_lower_6x_sj4000.scad, mono_lower_6x_sj4000.stl, mono_upper_6x_sj4000.scad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]
2016-05-07 tweak io cutout offset
    [mono_lower_6x_sj4000.scad, mono_lower_6x_sj4000.stl]
2016-05-07 flipped direction of rocker button cut out
    [mono_upper_6x_sj4000.scad, mono_upper_6x_sj4000.stl]
2016-05-07 add zenith module for sj4000
    [mono_zenith_sj4000.scad, mono_zenith_sj4000.stl]
2016-05-08 change from 10-32 screws to 6-32
    [mono_upper_6x_sj4000.scad, mono_upper_6x_sj4000.stl, mono_zenith_sj4000.scad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]
2016-05-08 added directional microphone cut-outs
    [mono_upper_6x_sj4000.scad, mono_upper_6x_sj4000.stl]
2016-05-08 fixed comment on wrong screw type
    [mono_upper_6x_sj4000.scad]
2016-05-08 modify 6-32 clearance holes to mitigate shrinking from post-print cooldown
    [mono_upper_6x_sj4000.scad, mono_upper_6x_sj4000.stl, mono_zenith_sj4000.scad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]
2016-05-09 modified 6-32 clearance holes again for proper PLA cooling skrinkage
    [mono_upper_6x_sj4000.scad, mono_upper_6x_sj4000.stl, mono_zenith_sj4000.scad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]
2016-05-09 widen zenith sj4000 tray for PLA cooldown shrink
    [mono_zenith_sj4000.scad, mono_zenith_sj4000.stl]
2016-05-09 move documentation images to new dir /doc
    [mono_lower_6x_sj4000.scad, mono_lower_6x_sj4000.stl, mono_lower_8x_sj4000.scad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]
2016-05-09 update bom
2016-12-14 initial image stitcher, a little sloppy, can optimize
    [main.cpp]
2017-01-22 LU decomp, flip getFeatures() args, chain homographies
